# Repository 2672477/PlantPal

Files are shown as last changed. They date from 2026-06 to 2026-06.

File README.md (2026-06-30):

# PlantPal

---

# NOTE

This project was originally started for FALLOUT and is now being transferred to Horizons with permission from both organizers.

No funding was received from FALLOUT, and the project was never approved there. Since FALLOUT uses Lookout, I kindly request that project hours be evaluated based on my submitted journal entries.

AI tools were used during the initial planning and brainstorming phase of this project. All hardware design, firmware development, CAD modeling, assembly, testing, and documentation reflect own work.

P.S. - Permission was taken from @phthallo for doing it this way.

---

# Overview

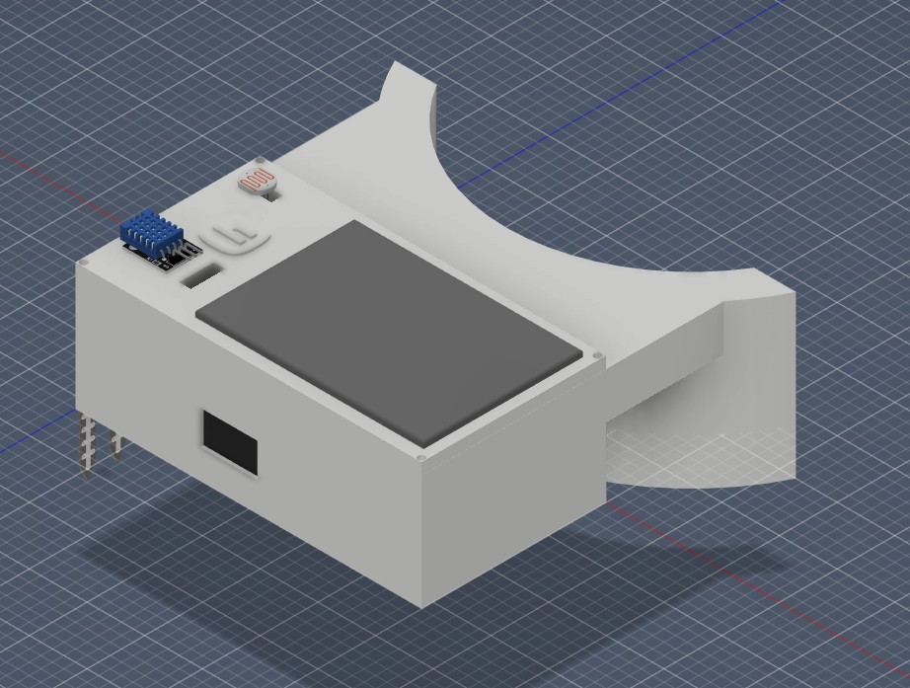
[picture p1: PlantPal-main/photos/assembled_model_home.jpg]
PlantPal


PlantPal is a solar-powered device that monitors the environment around a plant. It measures soil moisture, temperature, humidity, and light levels using an ESP32 and displays the plant's condition on a 0.96" OLED display.

Instead of showing raw sensor values, PlantPal displays simple expressions that make it easy to tell when a plant is healthy or needs attention. The goal was to make something that could be understood with a quick glance instead of opening an app or reading graphs.

The device runs from a rechargeable 18650 battery, while a small solar panel helps recharge it during the day.

---

# Why I Built It

I wanted to build a project that combined electronics, firmware, CAD, and 3D printing into one complete system.

While looking at existing plant monitoring projects, I noticed that most of them focused on displaying sensor values. That works well if you know what the numbers mean, but I wanted to try a different approach. Instead of expecting the user to interpret moisture percentages or light levels, PlantPal converts those readings into simple expressions on the display.

This project also gave me the opportunity to design my own enclosure, integrate solar charging, and build a complete embedded system instead of only testing sensors on a breadboard.

---

# Features

- Measures soil moisture
- Measures temperature and humidity
- Measures ambient light
- Displays the plant's condition on a 0.96" OLED display
- RGB LED status indicator
- Rechargeable 18650 battery
- Solar-assisted charging
- ESP32-WROOM-32 based hardware
- Custom designed 3D printed enclosure

---

# Project Gallery

## Fully Assembled Device

Main Assembly

## Side View

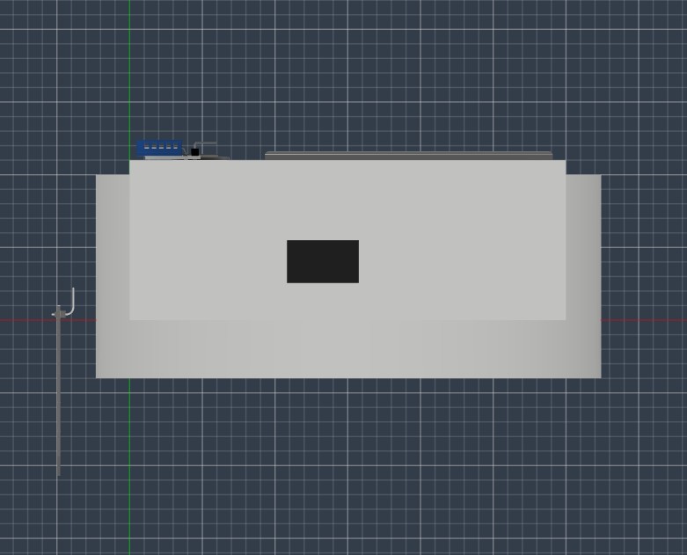
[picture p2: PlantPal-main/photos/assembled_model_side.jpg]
Side View


## Exploded View

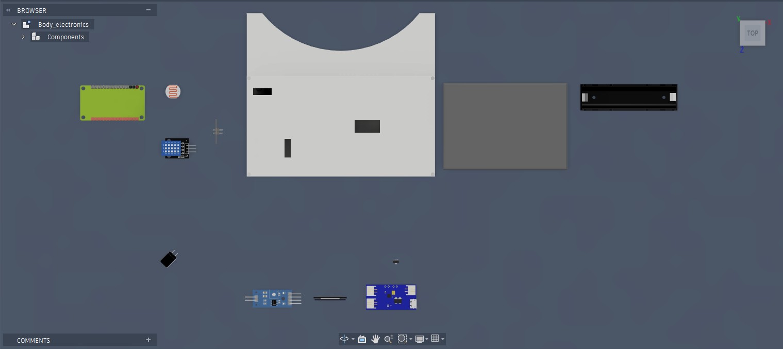
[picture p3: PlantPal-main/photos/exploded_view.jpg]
Exploded View


## Exploded View (Front)

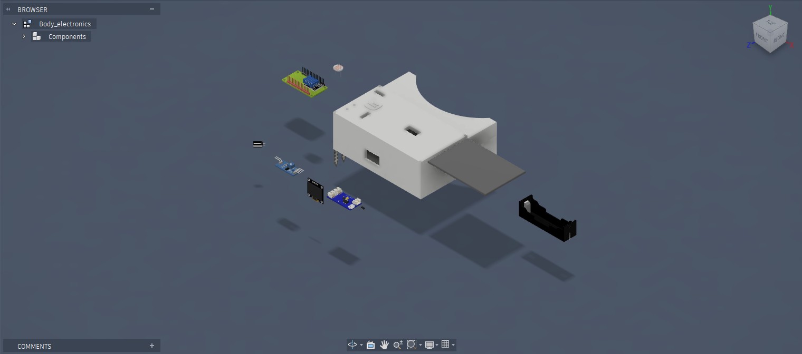
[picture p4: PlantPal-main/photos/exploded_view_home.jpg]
Exploded Front


## Exploded View (Side)

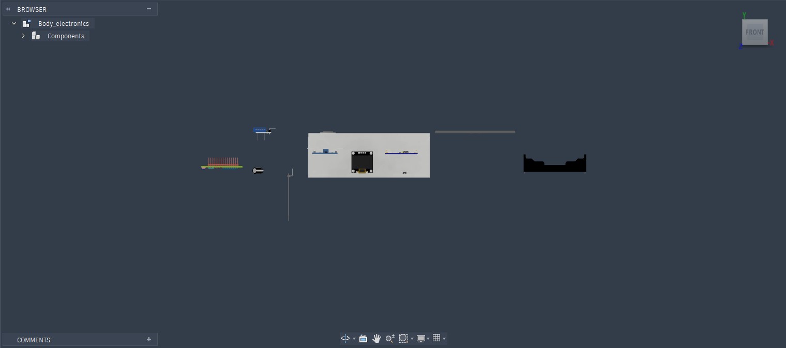
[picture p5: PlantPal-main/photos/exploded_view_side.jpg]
Exploded Side


These renders were useful while checking the fit of the internal components before printing the final enclosure.

---

# How It Works

PlantPal uses four sensors to monitor the plant's surroundings:

- Capacitive Soil Moisture Sensor
- AHT20 Temperature Sensor
- AHT20 Humidity Sensor
- BH1750 Light Sensor

Every few seconds, the ESP32 reads all four sensors and compares the values against predefined thresholds in the firmware.

Based on those readings, the firmware selects an expression that reflects the plant's overall condition. For example, dry soil or poor lighting will display an unhappy expression, while good growing conditions display a happy one.

The RGB LED also changes colour to match the current status, making it easy to check the plant from a distance.

Power is supplied by a rechargeable 18650 battery. A CN3065 solar charging board recharges the battery whenever the solar panel is exposed to sunlight.

---

# CAD Files

Designing the enclosure took several iterations because I needed to fit the battery, ESP32, display, charging circuit, sensors, and wiring into a compact space while keeping the device easy to assemble and service.

## Complete Assembly

- [STL File](PlantPal-main/cad/BODY_WITH_ELECTRONICS/Body_electronics.stl)

- [STEP File](PlantPal-main/cad/BODY_WITH_ELECTRONICS/Body_electronics.step)

## Individual Parts

All printable enclosure parts are available in:

```text
PlantPal-main/cad/PARTS
```

The repository also includes the source CAD files so the design can be modified or improved in the future.

---

# Hardware

PlantPal is built around an ESP32-WROOM-32 and uses commonly available components.

| Component | Purpose |
| --- | --- |
| ESP32-WROOM-32 | Main Controller |
| Capacitive Soil Moisture Sensor | Soil Moisture Measurement |
| AHT20 | Temperature & Humidity Measurement |
| BH1750 | Ambient Light Measurement |
| 0.96" OLED Display | Displays Plant Status |
| RGB LED | Visual Status Indicator |
| 18650 Battery | Main Power Source |
| CN3065 Solar Charger | Solar Battery Charging |
| HT7333-A LDO Regulator | 3.3V Voltage Regulation |
| 5V 2W Solar Panel | Solar Power Input |
| Custom 3D Printed Enclosure | Houses All Components |

---

# Bill of Materials

A complete list of components, supplier links, quantities, and prices is available here:

- [Bom.csv](PlantPal-main/Bom.csv)

The total hardware cost for this project is approximately **$18.39 USD**, excluding tools used during assembly.

---
# Wiring Diagram

I decided not to design a PCB for this version of PlantPal. Instead, all of the electronics are connected using hand wiring.

Before assembling everything, I recreated the circuit in KiCad to make sure all of the power and signal connections were correct. That made assembly much easier and helped catch mistakes before I started soldering.

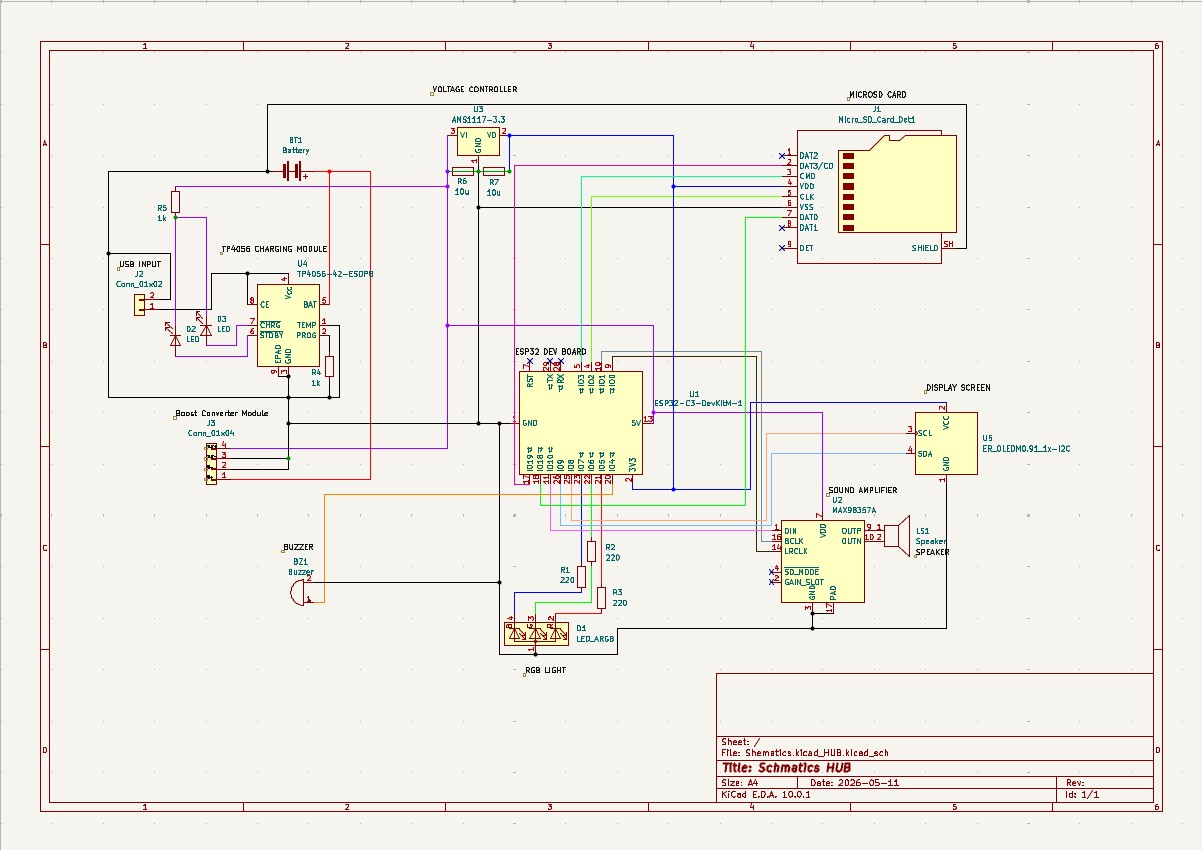
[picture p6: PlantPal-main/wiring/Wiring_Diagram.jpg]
Wiring Diagram


The wiring diagram includes:

- ESP32-WROOM-32
- Capacitive Soil Moisture Sensor
- AHT20 Temperature & Humidity Sensor
- BH1750 Light Sensor
- 0.96" OLED Display
- RGB LED
- CN3065 Solar Charging Circuit
- HT7333-A LDO Regulator
- 18650 Battery
- Solar Panel

Everything shown in the diagram matches the hardware used in the finished build.

---

# Building PlantPal

This repository includes the firmware, CAD files, wiring diagram, BOM, and assembly resources needed to recreate the project.

---

## 1. Print the Enclosure

Print all enclosure parts from:

```text
PlantPal-main/cad/PRINTING PARTS
```

After printing, install the M3 brass heat-set inserts into the enclosure.

The enclosure is designed around the components used in this build, making assembly straightforward while still allowing access for maintenance.

---

## 2. Prepare the Electronics

Use the BOM as a checklist and gather all required components.

Main components:

- ESP32-WROOM-32
- Capacitive Soil Moisture Sensor
- AHT20
- BH1750
- 0.96" OLED Display
- RGB LED
- CN3065 Solar Charger
- HT7333-A Regulator
- 18650 Battery
- Battery Holder
- Solar Panel

I tested each sensor individually before final assembly to avoid troubleshooting after everything was mounted.

---

## 3. Assemble the Hardware

Begin installing the components inside the enclosure.

The enclosure includes mounting locations for:

- ESP32
- OLED Display
- Battery Holder
- Charging Board
- Voltage Regulator

Fitting everything inside the enclosure took several layout revisions. The final design leaves enough room for wiring and can still be opened later if a component needs replacing.

---

## 4. Complete the Wiring

Follow the wiring diagram while soldering the connections.

Main connections include:

- I²C bus for the OLED, AHT20, and BH1750
- Soil moisture sensor output
- RGB LED outputs
- Battery connections
- Solar charging circuit
- 3.3V power rail

Double-check all power connections and verify there are no shorts before connecting the battery.

---

## 5. Upload the Firmware

The firmware is located in:

```text
PlantPal-main/firmware
```

Upload it using Arduino IDE or PlatformIO.

The firmware handles:

- Reading all sensors
- Processing the sensor values
- Choosing the correct plant expression
- Updating the OLED display
- Controlling the RGB LED

Once uploaded, the ESP32 starts monitoring automatically.

---

# Using PlantPal

After startup, the device continuously monitors the plant and updates the display every few seconds.

1. Insert the soil moisture sensor into the plant pot.
2. Place the device where the solar panel can receive sunlight.
3. Power on the device.
4. Wait a few seconds for the first sensor readings.

Once running, PlantPal updates automatically.

The OLED displays the current condition of the plant, while the RGB LED provides a quick status indication that can be seen from a distance.

No app or additional setup is required after powering on.

---

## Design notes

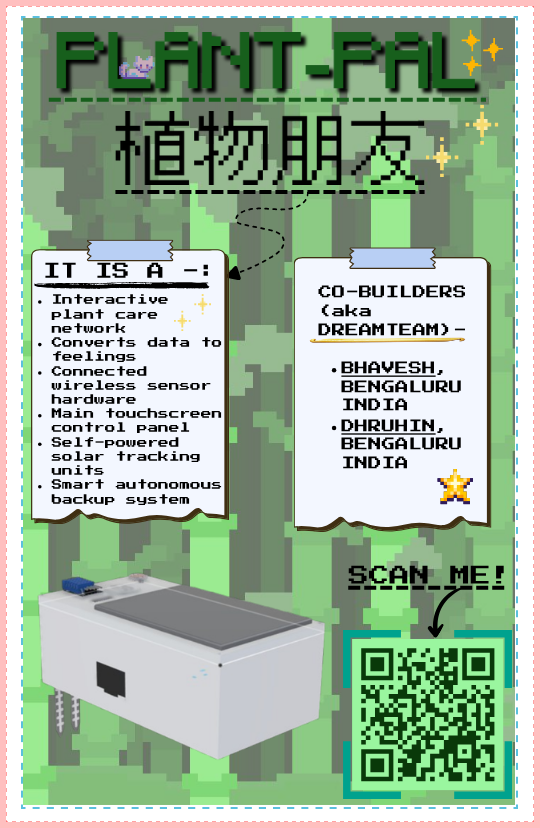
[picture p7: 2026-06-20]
PlantPal-main/zine/ZINE_PLANT-PAL.png

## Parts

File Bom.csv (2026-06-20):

Product Name | Description | Quantity | Unit Price($) | Total Price($) | URL
ESP32-WROOM-32 Dev Board | WiFi + BLE Microcontroller | 1 | 4.06 | 4.06 | https://robocraze.com/products/nodemcu-32-wifi-bluetooth-esp32-development-board30-pin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
Capacitive Soil Moisture Sensor v1.2 | Soil Moisture Sensor | 1 | 0.65 | 0.65 | https://www.flipkart.com/ziobotics-5v-soil-moisture-sensor-module-pack-1-plant-monitoring-smart-irrigation-electronic-components-hobby-kit/p/itm347f17fdb44c8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
AHT20 | Temperature Sensor | 1 | 1.34 | 1.34 | https://robocraze.com
GY-302 BH1750 | Light Intensity Sensor | 1 | 1.42 | 1.42 | https://robocraze.com/products/gy-302-bh1750-light-intensity-module?_pos=1&_sid=4a6498e1f&_ss=r
0.96' OLED | Display | 1 | 1.69 | 1.69 | https://robocraze.com/products/0-96in-oled-display-module-4pin?_pos=1&_sid=8ccd9ded7&_ss=r
18650 Li-ion Battery | Battery | 1 | 0.73 | 0.73 | https://robocraze.com/products/3-7v-2000mah-18650-li-ion-battery?_pos=1&_sid=a3bd80eec&_ss=r
18650 Li-ion Battery Holder | Battery Holder | 1 | 0.17 | 0.17 | https://robocraze.com/products/18650-1-cell-holder?_pos=2&_sid=ca0d8ced4&_ss=r
TP4056 Charging Module | USB-C Backup Charger Module | 1 | 0.15 | 0.15 | https://robocraze.com/products/tp4056-battery-charger-c-type-module-with-protection-1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
CN3065 Solar Charger Board | Dedicated Solar MPPT Management | 1 | 0.88 | 0.88 | https://robu.in/product/mini-solar-lipo-charger-board/?gad_source=1&gad_campaignid=17427802559
HT7333-A LDO Regulator | Ultra-Low Power 3.3V Regulator | 1 | 0.48 | 0.48 | https://robu.in/product/ht7333-a-holtek-semicon-250ma-fixed-3-3v-positive-electrode-12v-sot-89-3-voltage-regulators-linear-low-drop-out-ldo-regulators-rohs/
16V Radial Electrolytic Capacitor (470uF) | Wi-Fi Power Spike Smoother | 1 | 0.18 | 0.18 | https://robu.in/product/16yxf470mffc10x12-5-rubycon-470uf-16v-160mω100khz-±20-580ma100khz-plugind10xl12-5mm-aluminum-electrolytic-capacitors-leaded-rohs/?gad_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
10k Ohm Quarter Watt Resistors | Pull-up & LDR Voltage Divider | 1 | 0.14 | 0.14 | https://robocraze.com/products/10k-resistor-pack-of-10?_pos=1&_sid=c78a5a957&_ss=r
220 Ohm Quarter Watt Resistors | RGB LED Current Limiters | 1 | 0.095 | 0.095 | https://robocraze.com/products/220-ohm-resistor-pack-of-10?_pos=1&_sid=8a82cca51&_ss=r
5V - 2W Solar Panel | Solar Panel | 1 | 0.98 | 0.98 | https://quartzcomponents.com/products/portable-mini-solar-panel-1-1w-6v-180ma-99-x-69mm?variant=44789436252394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
Male to Female Jump Wires | Wires | 1 | 0.45 | 0.45 | https://robocraze.com/products/f2m-jumper-wires-20cm-40pcs?variant=40192519110809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
Male to Male Jump Wires | Wires | 1 | 0.49 | 0.49 | https://robocraze.com/products/m2m-jumper-wires-20cm-40pcs?_pos=1&_sid=2e3cb64b0&_ss=r
Female to Female Jump Wires | Wires | 1 | 0.45 | 0.45 | https://robocraze.com/products/f2f-jumper-wires-20cm-40pcs?_pos=1&_sid=51c4faba8&_ss=r
M3 X 5 mm Brass Heat Threaded Round Insert Nut | Heat-Set Inserts | 10 | 0.025 | 0.25 | https://onlyscrews.in/products/m3-x-5mm-brass-threaded-inserts-dia-3mm-length-5mm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
M3 x 8mm Button Head Screws | Enclosure Assembly Fasteners | 10 | 0.028 | 0.28 | https://onlyscrews.in/products/m3-x-8mm-hex-allen-button-head-hight-tensile10-9-black-oxide-screw-dia-3mm-length-8mm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
3d Printed Enclosure | Custom Enclosure | 1 | 3.50 | 3.50 | forms.hackclub.com/print-legion-signup
Total |  |  |  | 18.385

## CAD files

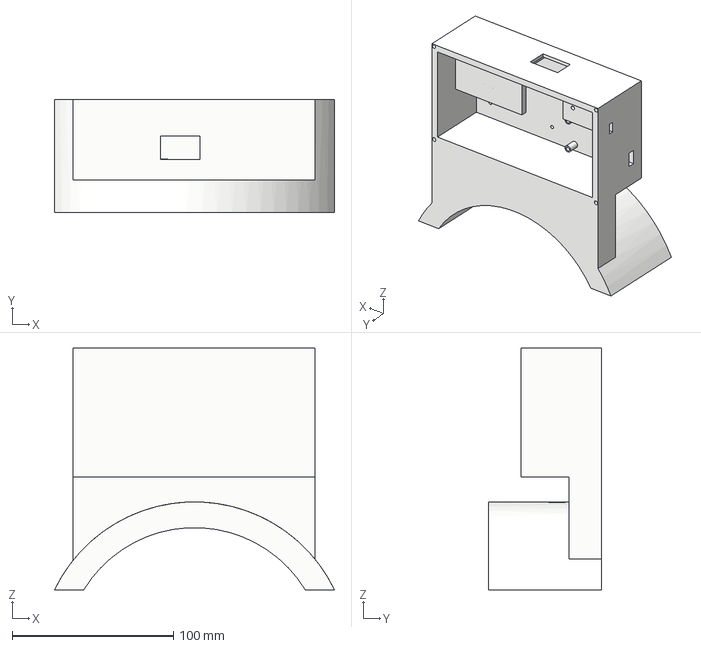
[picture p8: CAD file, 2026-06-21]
PlantPal-main/cad/PRINTING PARTS/BODY/Main_Body.step
173.8 x 70.0 x 150.0 mm

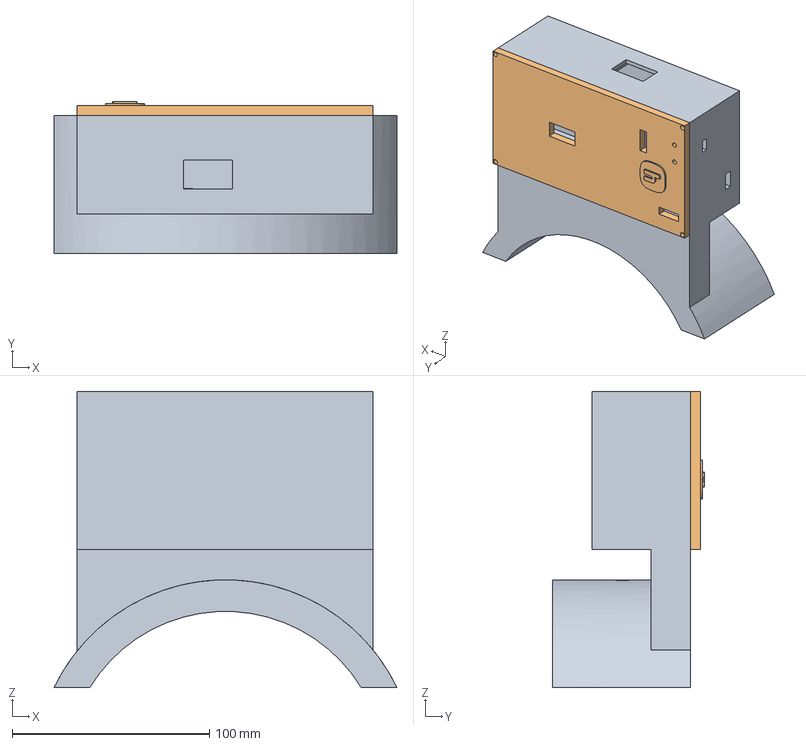
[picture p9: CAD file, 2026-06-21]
PlantPal-main/cad/BODY/Body_electronics.step
173.8 x 77.0 x 150.0 mm

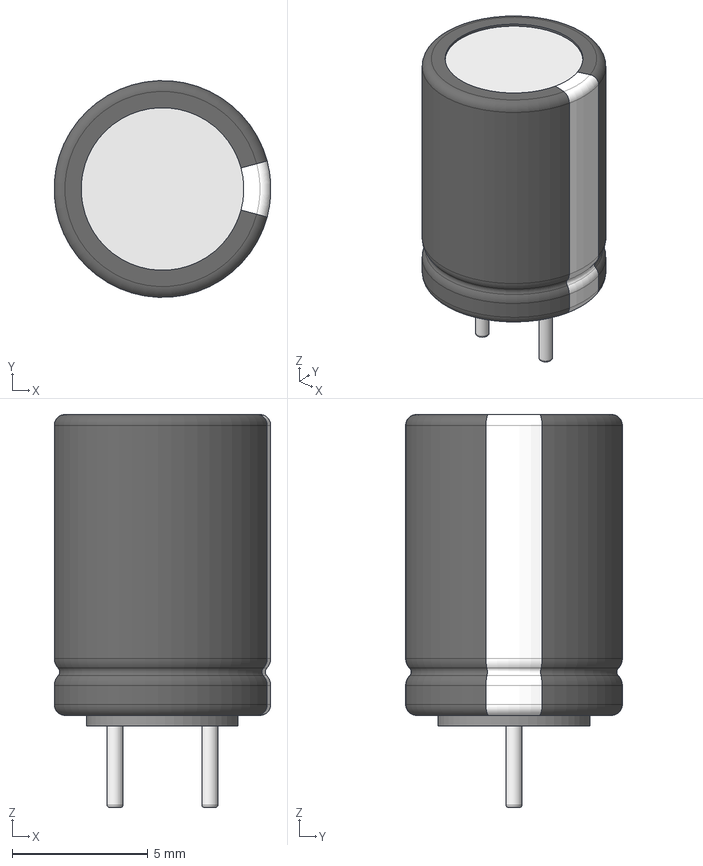
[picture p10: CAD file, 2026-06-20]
PlantPal-main/cad/PARTS/Capacitor/Aluminum_electrolytic_capacitor_radial_D8_H11.5_PinD0.6_Pitch3.5_nominal_black.step
7.99 x 7.99 x 14.5 mm

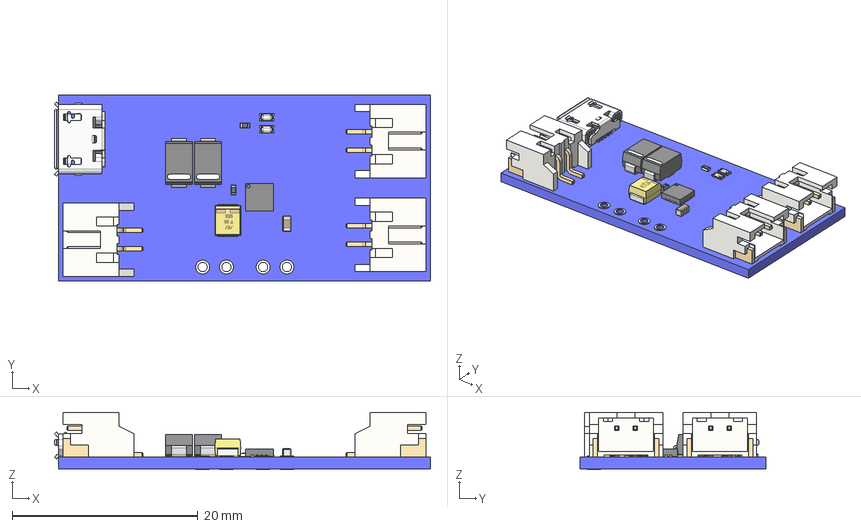
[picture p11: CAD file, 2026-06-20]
PlantPal-main/cad/PARTS/CN3065 Solar Charger/CN3065 Solar Charger board.step
40.4 x 20.0 x 6.17 mm

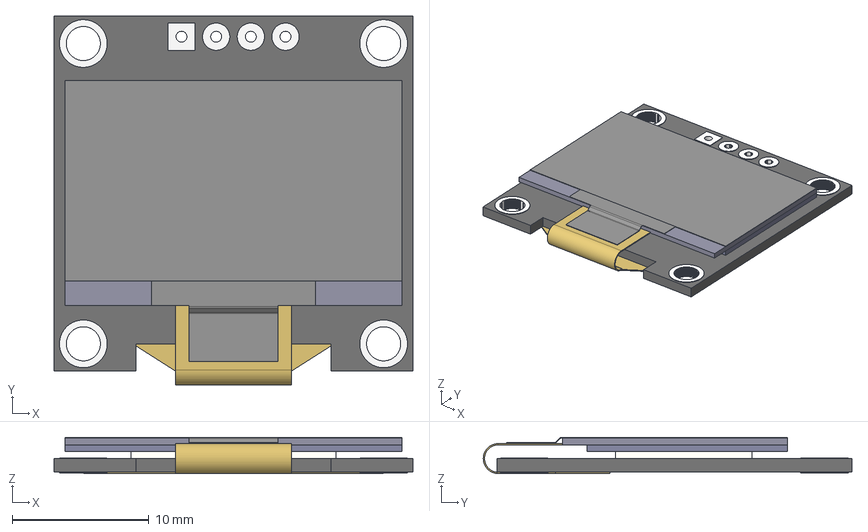
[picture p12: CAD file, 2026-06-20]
PlantPal-main/cad/PARTS/Display_OLED/Display_OLED_0.96_128x64.step
26.3 x 27.0 x 2.65 mm

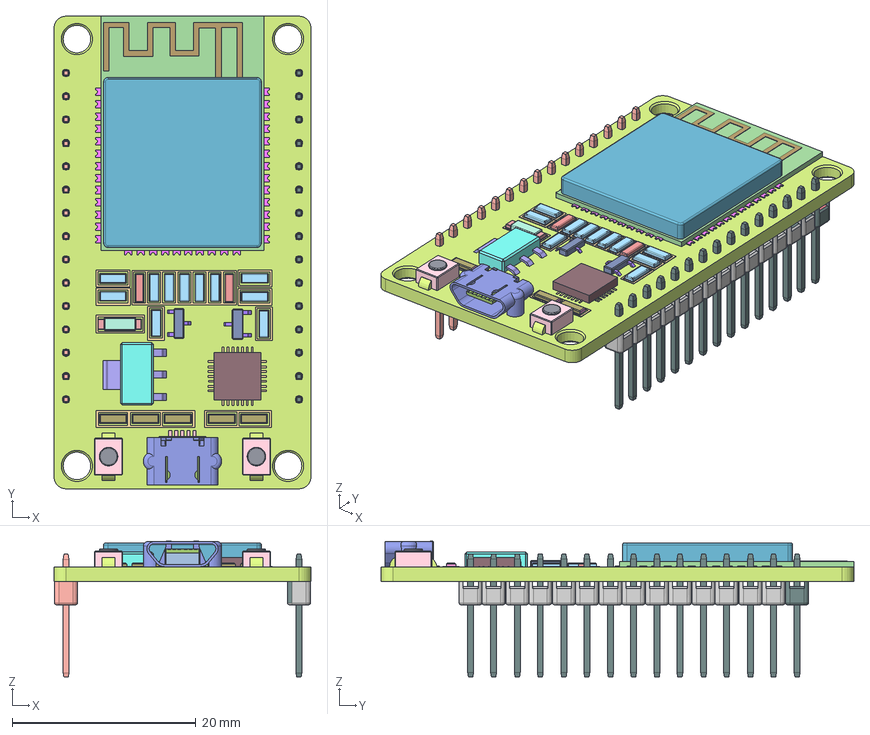
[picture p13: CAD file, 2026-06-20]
PlantPal-main/cad/PARTS/ESP32 dev kit/ESP32 dev Kit v1.step
28.0 x 51.5 x 14.8 mm

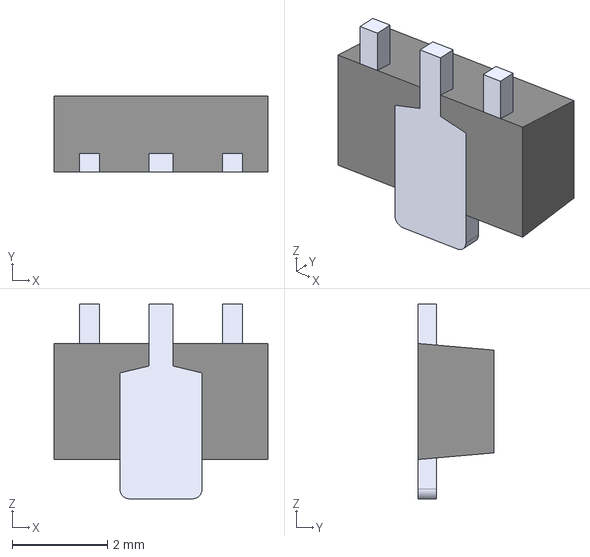
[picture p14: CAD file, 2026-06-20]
PlantPal-main/cad/PARTS/HT7333--3DModel/HT7333--3DModel-STEP-510211.step
4.50 x 1.60 x 4.09 mm

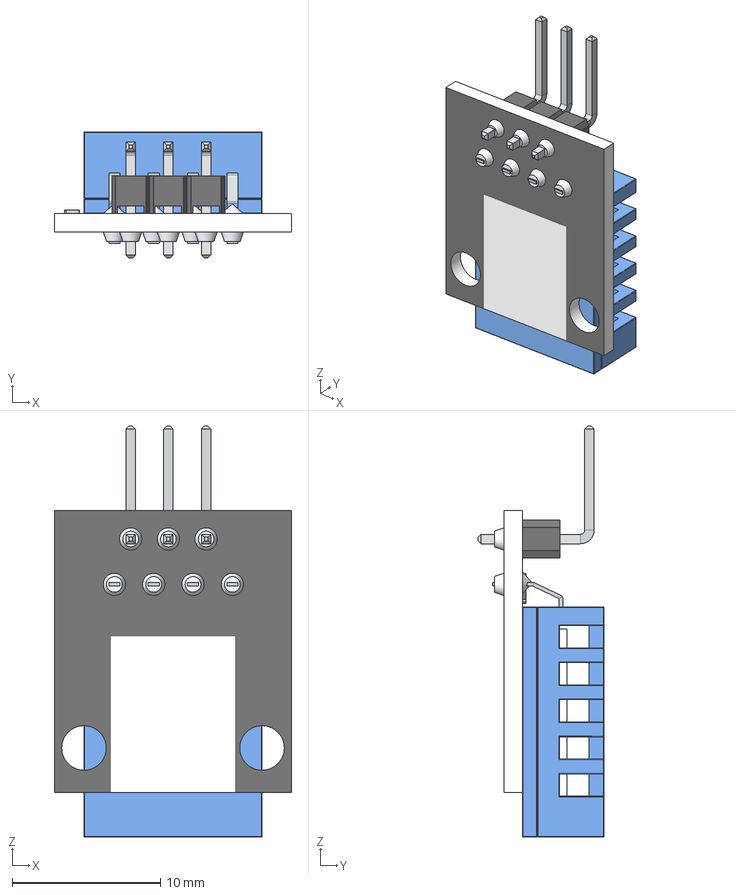
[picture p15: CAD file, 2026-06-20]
PlantPal-main/cad/PARTS/KY-015/KY-015 (1).step
16.0 x 8.50 x 27.7 mm

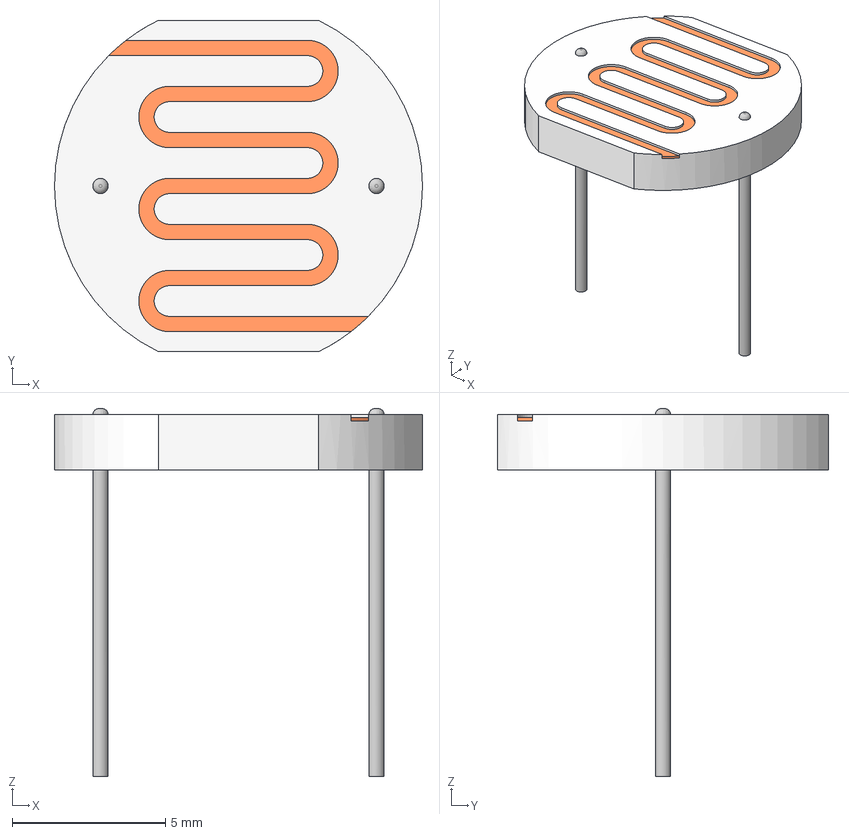
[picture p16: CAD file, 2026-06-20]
PlantPal-main/cad/PARTS/LDR12/LDR12.step
12.0 x 10.8 x 12.0 mm

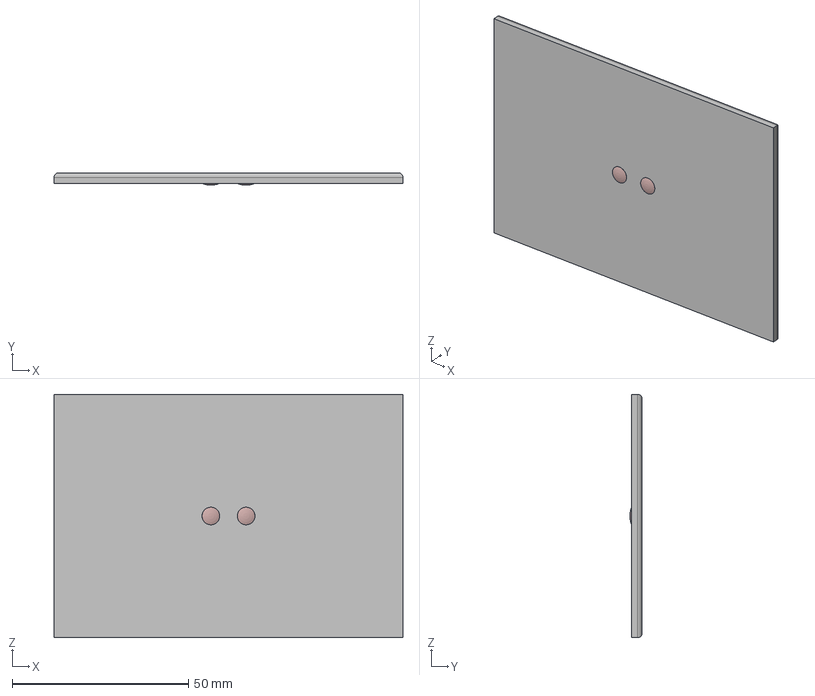
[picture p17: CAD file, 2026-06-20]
PlantPal-main/cad/PARTS/Polycrystalline Solar Panel/Polycrystalline Solar Panel, 5 V, 200 mA.step
99.0 x 3.51 x 69.0 mm

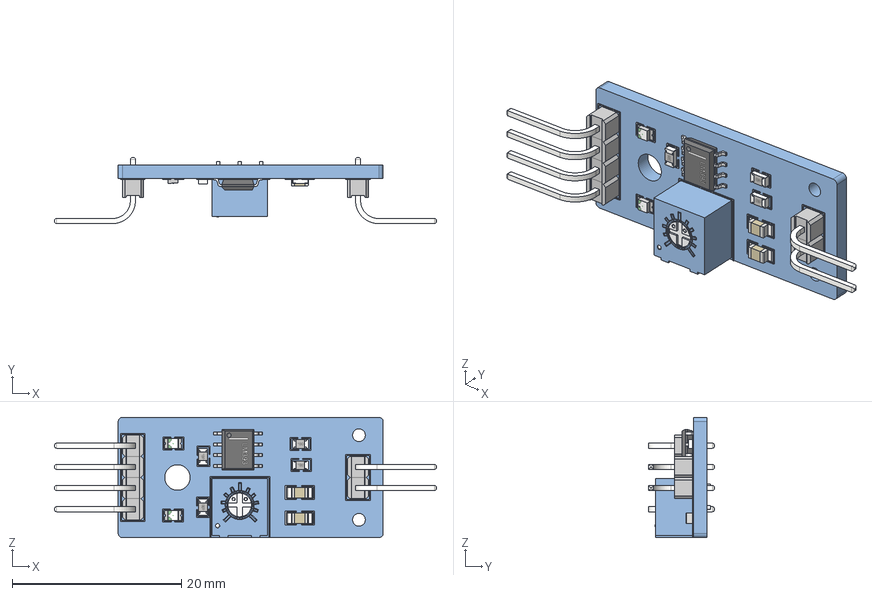
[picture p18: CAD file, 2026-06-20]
PlantPal-main/cad/PARTS/Soil Moisture Sensor Board/Soil Moisture Sensor Board.step
45.1 x 7.80 x 14.2 mm

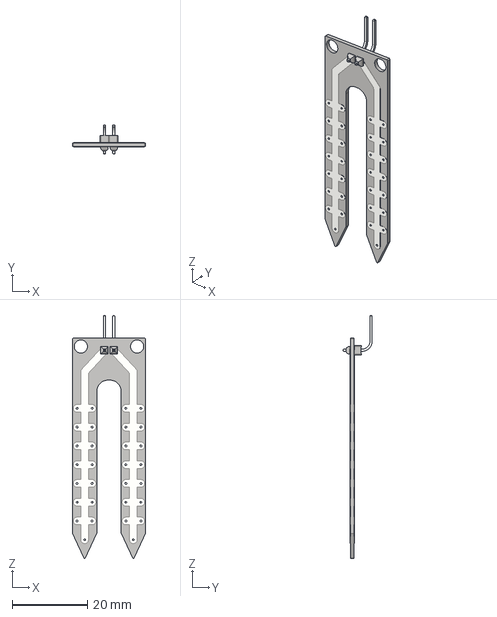
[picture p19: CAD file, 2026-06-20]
PlantPal-main/cad/PARTS/Soil Moisture Sensor/soil moisture sensor.step
19.5 x 7.80 x 64.7 mm

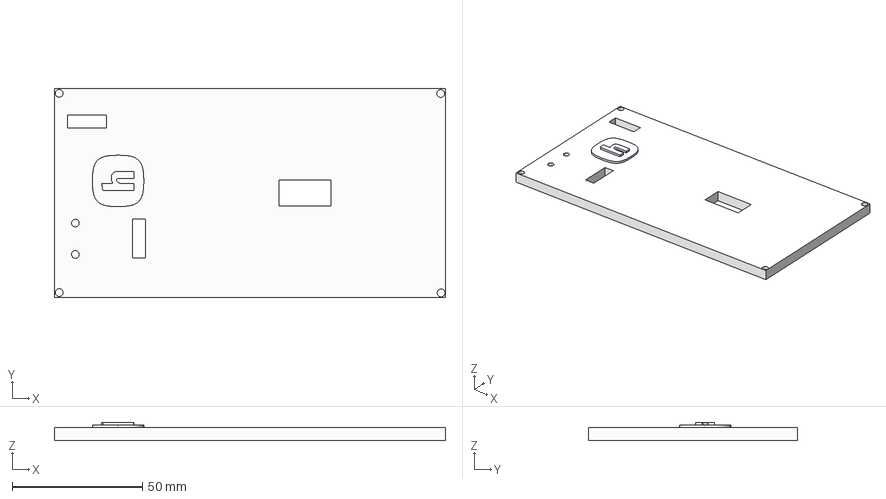
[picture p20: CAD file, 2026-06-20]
PlantPal-main/cad/PRINTING PARTS/LID/Lid.step
150.0 x 80.0 x 7.00 mm

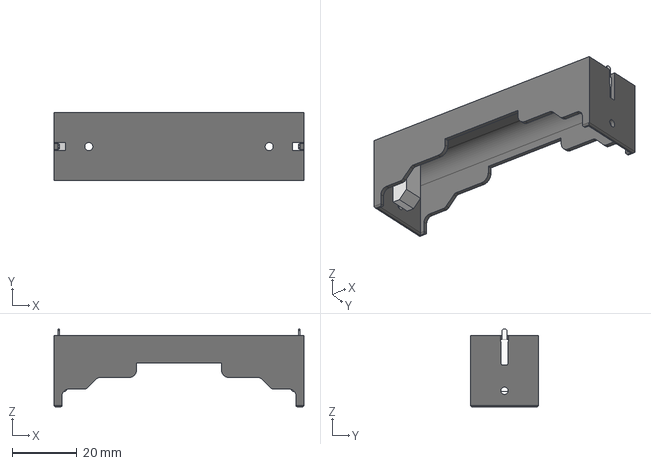
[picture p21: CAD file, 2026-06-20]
PlantPal-main/cad/PARTS/Battery Holder/18650-battery-and-holder-02b.step
77.3 x 21.0 x 24.1 mm

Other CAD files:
PlantPal-main/cad/PARTS/Battery Holder/18650-battery-and-holder-02b.f3d
PlantPal-main/cad/PARTS/CN3065 Solar Charger/CN3065 Solar Charger board.f3d
PlantPal-main/cad/PARTS/Capacitor/Aluminum_electrolytic_capacitor_radial_D8_H11.5_PinD0.6_Pitch3.5_nominal_black.f3d
PlantPal-main/cad/PARTS/Display_OLED/Display_OLED_0.96_128x64.f3d
PlantPal-main/cad/PARTS/ESP32 dev kit/ESP32 dev Kit v1.f3d
PlantPal-main/cad/PARTS/HT7333--3DModel/HT7333--3DModel-STEP-510211.f3d
PlantPal-main/cad/PARTS/KY-015/KY-015 (1).f3d
PlantPal-main/cad/PARTS/LDR12/LDR12.f3d
PlantPal-main/cad/PARTS/Polycrystalline Solar Panel/Polycrystalline Solar Panel, 5 V, 200 mA.f3d
PlantPal-main/cad/PARTS/Soil Moisture Sensor Board/Soil Moisture Sensor Board.f3d
PlantPal-main/cad/PARTS/Soil Moisture Sensor/soil moisture sensor.f3d
PlantPal-main/cad/PRINTING PARTS/BODY/Main_Body.f3d
PlantPal-main/cad/PRINTING PARTS/LID/Lid.f3d

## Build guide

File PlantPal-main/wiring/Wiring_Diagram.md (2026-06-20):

# 🧠 PLANTPAL NODE CONNECTIONS

### ESP32-C3 DEV BOARD
* **3.3V Pin** <- **HT7333-A VOUT** (Direct low-power supply)
* **GND** <- Common GND
* **470µF Capacitor (+)** -> Solder directly to ESP32 **3.3V Pin**
* **470µF Capacitor (-)** -> Solder directly to ESP32 **GND Pin**

---

### SOIL MOISTURE SENSOR (Power-Gated)
* **VCC** -> **IO2** (ESP32 pin controls power ON/OFF)
* **GND** -> GND
* **DO** -> Not Connected
* **AO** -> **IO0**

---

### LIGHT INTENSITY SENSOR (LDR)
* **Top Pin** -> **3.3V Pin**
* **Bottom Pin** -> **IO1**
* **IO1** -> 10kΩ Resistor -> GND

---

### DHT11 TEMPERATURE + HUMIDITY SENSOR (Power-Gated)
* **1(VDD)** -> **IO3** (ESP32 pin controls power ON/OFF)
* **2(DATA)** -> **IO4**
* **4(GND)** -> GND
* **DATA** -> 10kΩ Resistor -> **IO3** (Pull-up connects to gated power)

---

### RGB LED
* **1(GND)** -> GND
* **2(RED)** -> 220Ω Resistor -> **IO5**
* **3(GREEN)** -> 220Ω Resistor -> **IO6**
* **4(BLUE)** -> 220Ω Resistor -> **IO7**

---

### 0.96" OLED DISPLAY (Power-Gated)
* **1(GND)** -> GND
* **2(VCC)** -> **IO10** (ESP32 pin controls power ON/OFF)
* **3(SCL)** -> **IO8**
* **4(SDA)** -> **IO9**

---

### SOLAR PANEL
* **+VE** -> **CN3065 VIN**
* **-VE** -> **CN3065 GND**

---

### SOLAR CHARGING MODULE (CN3065)
* **TEMP** -> GND
* **ISET** -> 2kΩ Resistor -> GND
* **GND** -> GND
* **VIN** -> Solar Panel +
* **BAT** -> Battery +
* **FB** -> BAT
* **VIN** -> 10µF Capacitor -> GND
* **BAT** -> 10µF Capacitor -> GND
* **VIN** -> 1kΩ Resistor -> LED -> DONE
* **VIN** -> 1kΩ Resistor -> LED -> CHRG

---

### TP4056 BATTERY CHARGING MODULE (USB-C Backup)
* **TEMP** -> GND
* **PROG** -> 1kΩ Resistor -> GND
* **GND** -> GND
* **VCC** -> USB-C 5V
* **BAT** -> Battery +
* **CE** -> VCC
* **EPAD** -> GND Copper Plane
* **VCC** -> 1kΩ Resistor -> LED -> STDBY
* **VCC** -> 1kΩ Resistor -> LED -> CHRG

---

### 18650 BATTERY
* **+VE** -> TP4056 BAT+ / CN3065 BAT+ / **HT7333-A VIN**
* **-VE** -> GND

---

### HT7333-A LDO REGULATOR 
* **Pin 1 (GND)** -> Common GND
* **Pin 2 (VIN)** -> **Battery +**
* **Pin 3 (VOUT)** -> **ESP32 Dev Board 3.3V Pin**

---

### 🔌 COMMON GROUND
ALL GND CONNECTIONS MUST BE CONNECTED TOGETHER:
* ESP32
* TP4056
* Battery (-)
* OLED
* RGB LED
* DHT11
* LDR (via 10kΩ Resistor)
* Moisture Sensor
* Solar Charging Module
* HT7333-A (Pin 1)
* 470µF Buffer Capacitor (-)

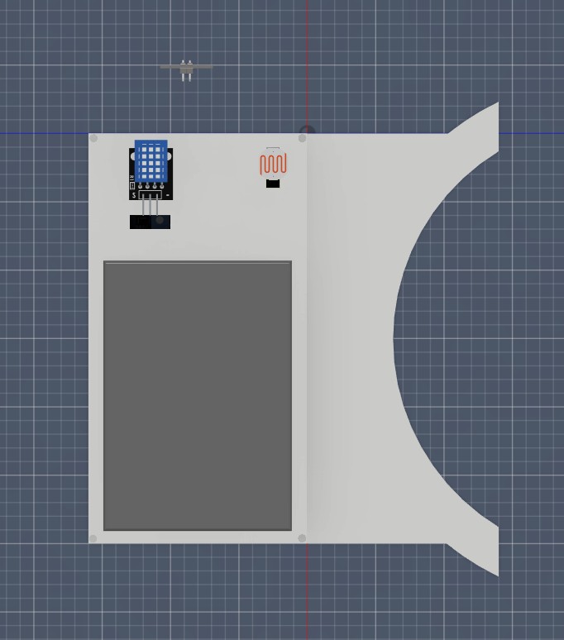
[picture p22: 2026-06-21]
PlantPal-main/photos/assembled_model_top.jpg

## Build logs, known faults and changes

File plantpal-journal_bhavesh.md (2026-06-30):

## NOTE: 
The remaining journal entries are of my teammate, thus are not included in my journal as fallout takes both together in one. These are all my hrs/journals. I have taken permission from Horizons team to do this.
Thank you!
This project was originally started for Fallout and is now being transferred to Horizons with permission from both organisers.
No funding was received from Stasis, and the project was never approved there. Since Fallout uses LOOKOUT, I kindly request that project hours be evaluated based on my submitted journal entries.
Thank you for your consideration.
## Total time spend
### FALLOUT HRS-37.9 hrs
### HACKATIME HRS-0.9
## TOTAL=38.8 HRS

# PlantPal — Journal Export

- Exported at: 2026-06-20T16:10:05Z
- Project ID: 2370
- Entries: 23

## Entry 3
- ID: 5917
- Author: bhaveshtushar123
- Created At: 2026-05-07T16:06:18Z

### Content

today was mostly focused on understanding the electronics and planning side of the new project with Dhruhin <3. we finalized a rough component list for both the PlantPal node and hub systems, which honestly made the whole idea feel way more real instead of just random thoughts on paper. we discussed how sensors, displays, power modules, and communication between the two ESP32 boards would work together.

i also spent time learning schematics properly and understanding how components connect logically before actually wiring anything. after that i downloaded KiCAD for the first time and started exploring the software for making schematics and future pcb work. ngl it looked super confusing at first bruh, but after watching tutorials and clicking around it slowly started making sense.

not a huge building day physically, but definitely important because now i understand the project architecture and electronics workflow way better yay.



### Recording Links

- https://lookout.hackclub.com/api/media/5ab33579-50ad-4a1c-97a9-db52b238f06b/video.mp4

## Entry 5
- ID: 6108
- Author: bhaveshtushar123
- Created At: 2026-05-08T16:37:24Z

### Content

Today I worked on the KiCad schematic again. Added the ESP32, OLED display, RGB LED, moisture sensor, temperature sensor, light sensor, solar charging module, battery charging module, and battery. Did most of the GND connections too, which took longer than expected because of all the wires crossing everywhere.

Also connected some parts of the solar panel circuit to the charging module. Added resistors and capacitors where needed. Mostly spent time moving things around and checking connections because some stuff was connected wrong the first time.

Overall, it was just schematic work for most of the day.

Schmatics-:



### Recording Links

- https://lookout.hackclub.com/api/media/1f7b8eaa-c1c9-4452-80d6-fc069befb9ee/video.mp4
- https://lookout.hackclub.com/api/media/6279dd45-151a-4eea-8f6b-39d9115646f6/video.mp4

## Entry 7
- ID: 6278
- Author: bhaveshtushar123
- Created At: 2026-05-09T15:53:52Z

### Content

Today I’ve been working on the TP4056 charging circuit in KiCad. Connected the battery, 5V input, GND and the BAT pin connections correctly. Also added the charging and standby LEDs with the resistors so that the charging status can be shown physically later.

Spent most of the time checking the pin connections as the TP4056 pins were easy to mix up. Had to redo some wires after seeing a couple of mistakes in the layout. wired up the PROG pin resistor as well, and did some cleanup of the schematic to make the wiring look less confusing.

I mostly worked on charging circuits today and fixed small connection problems.




### Recording Links

- https://lookout.hackclub.com/api/media/37b36937-bbb7-4d18-b73c-07ce0e945bd3/video.mp4

## Entry 8
- ID: 6447
- Author: bhaveshtushar123
- Created At: 2026-05-10T16:13:37Z

### Content

Today was mostly wiring work for the PlantPal schematic. Connected almost all the remaining parts including the sensors, OLED display, RGB LED, TP4056 module, solar charging module, battery, and boost converter with the ESP32. Spent a lot of time routing wires properly because the schematic was getting messy and some connections kept overlapping.

After that I went back and rechecked the whole circuit again to make sure the current flow and power connections actually made sense. Also had to decide GPIO pins properly depending on analog support, I2C, PWM, and avoiding ESP32-C3 boot issue pins. Found and fixed a few wrong connections during checking too.

Also helped another Hack Cluber for a bit because she DM’d me asking about KiCad and wiring problems.

SCHEMATICS-


NOTEPAD-



### Recording Links

- https://lookout.hackclub.com/api/media/7065059a-00b2-42a5-b121-e7af8bd39af5/video.mp4
- https://lookout.hackclub.com/api/media/04546d30-af83-4f61-9567-41a2cfead865/video.mp4

## Entry 10
- ID: 6610
- Author: bhaveshtushar123
- Created At: 2026-05-11T16:34:08Z

### Content

Journal Entry, Day __

Today, I color-coded much of the node wiring in KiCad to make the schematic easier to read. The wires became confusing after I added all the sensors, charging modules, OLED, RGB LED, and power connections. Then, I rechecked the entire node schematic to confirm the current flow, GPIO pins, and power routing were correct.

After that, I completed most of the hub schematic, including the audio amplifier, speaker, OLED, MicroSD, regulator, TP4056, and ESP32 connections. I spent some time double-checking all the connections because there were many overlapping communication and power lines.

I also exported the schematic files and organized them in the file explorer before starting CAD tomorrow.
NODE-


HUB-


### Recording Links

- https://lookout.hackclub.com/api/media/11ef0c32-c5c4-484f-8737-61aee74f9471/video.mp4
- https://lookout.hackclub.com/api/media/53a89df3-de79-4e76-8606-135fc017e0b2/video.mp4
- https://lookout.hackclub.com/api/media/eacdf0fa-082c-4c86-b559-8ba7f5f7aea2/video.mp4

## Entry 14
- ID: 6958
- Author: bhaveshtushar123
- Created At: 2026-05-13T17:38:13Z

### Content

Today I started making a rough layout of the project in Paint first so I could plan where all the electronics would actually fit before doing proper CAD. It helped me figure out spacing and placement for the ESP32, battery, sensors, OLED, charging module, boost converter, and wiring paths without making the Autodesk file messy immediately.
After that I started adding all the electronics into Autodesk and placing components roughly inside the model. Most of the time went into checking dimensions, arranging parts so they would physically fit, and trying to keep wiring space available. Also had to keep changing placements because some components were overlapping or taking more space than expected.




### Recording Links

- https://lookout.hackclub.com/api/media/19227290-0214-49de-aecf-73635e859d86/video.mp4
- https://lookout.hackclub.com/api/media/39ec9275-5b34-49c3-b704-0bd5c9d1d179/video.mp4

## Entry 16
- ID: 7079
- Author: bhaveshtushar123
- Created At: 2026-05-14T13:52:37Z

### Content

Today I worked more on the Autodesk model and started adding some of the main electronics into the enclosure. Added the OLED display, ESP32, MT3608 boost converter, 18650 battery, and AMS1117 regulator roughly in their positions to check spacing and layout. Had to move parts around a lot because some components were larger than expected and the wiring space was getting cramped.

Also made an internal platform/support structure inside the model so more electronics could be mounted properly instead of everything floating around randomly. Spent some time adjusting heights and placements so components could stack better and still leave space for wires and future additions.





### Recording Links

- https://lookout.hackclub.com/api/media/3a23301c-8656-4666-a354-427e7738438a/video.mp4

## Entry 18
- ID: 7276
- Author: bhaveshtushar123
- Created At: 2026-05-15T15:57:34Z

### Content

Today, I focusd mainly on the CAD model and completed most of the main structure for the node. I added more components to the enclosure, including the DHT11 sensor, LDR, solar panel, and the Hack Club logo to the design. I spent a lot of time adjusting placements and dimensions to ensure everything fit well without overlapping internally. I also created holes and cutouts for wires, screws, sensors, and mounting points since the enclosure was mostly solid before. I changed the render and material settings too, making the model look cleaner and easier to visualise. Most of the CAD work is done now, aside from a few small adjustments and final details. Also added lid, forgot that part.

ELECTRONICS-

LID-

MAIN-


### Recording Links

- https://lookout.hackclub.com/api/media/62b85ff0-1776-4982-bd3c-866d370d4d17/video.mp4
- https://lookout.hackclub.com/api/media/e16ffa62-e9bf-44ba-a7a8-ef37866cbf37/video.mp4
- https://lookout.hackclub.com/api/media/b78c2c9e-9d7b-4c64-90aa-9508c52582d8/video.mp4

## Entry 21
- ID: 14029
- Author: bhaveshtushar123
- Created At: 2026-06-14T17:11:51Z

### Content

Today I started working on the Zine for the project. Since I had never really made one before, a lot of the time went into figuring out how everything should be laid out and what information was actually important to include. I worked on organizing the content, planning pages, and trying to make it look less cluttered while still explaining the project properly.

During Fallout Lock-In 2, I also learned how to use Figma from Rehan. He showed me some of the basics, like working with frames, arranging elements, and making designs look cleaner. I used some of those things while working on the Zine.

Apart from that, I spent time hanging out with Renran and a few other people during the event. We talked, messed around, and had a lot of fun while working, which made the whole session much more enjoyable.

zine-


### Recording Links

- https://lookout.hackclub.com/api/media/140d17be-c9f9-49db-b658-40af07913806/video.mp4
- https://lookout.hackclub.com/api/media/5c043b82-5789-4a20-974e-6d6c678c438f/video.mp4

## Entry 22
- ID: 14574
- Author: bhaveshtushar123
- Created At: 2026-06-16T17:07:38Z

### Content

Journal Entry — Day __

Today I worked more on the CAD model and made a few important design changes before moving closer to a final version. I went through the enclosure again and checked that all the screw holes were properly placed and aligned so the different parts could be assembled securely. I also adjusted some dimensions and placements to make sure the components would fit correctly inside the enclosure.

On the electronics side, I updated the design by simplifying the power system. I removed the MT3608 boost converter and AMS1117 regulator from the project and replaced them with an HT7333-A LDO regulator along with a 16V radial electrolytic capacitor. This made the circuit simpler, reduced the number of components, and helped save space inside the enclosure. After making the changes, I updated the CAD layout to match the new electronics arrangement and checked that everything still fit properly.



### Recording Links

- https://lookout.hackclub.com/api/media/3869ff6c-a1b9-4fa5-9c12-3c610f5561af/video.mp4

## Entry 23
- ID: 15568
- Author: bhaveshtushar123
- Created At: 2026-06-20T12:16:36Z

### Content

Today was mostly focused on documentation and final project organization. I spent a good amount of time going through the entire project again and updating the README so it accurately reflected the current version of PlantPal. Since the hub had been removed from the project, I had to rewrite several sections, update the hardware list, BOM, architecture, setup instructions, and add proper descriptions for how the device works.

I also organized the repository structure, added links to the CAD files, wiring diagrams, and project assets, and made sure all the renders and images were included in the documentation. A lot of time went into deciding what information was actually important and removing sections that were either outdated or repetitive.

Along with that, I reviewed the BOM again, checked component selections, and verified that the documentation matched the latest CAD and electronics design. By the end of the day, the project felt much more complete and easier for someone new to understand without needing to open additional files.


### Recording Links

- https://lookout.hackclub.com/api/media/ad1d62ed-e7c8-4d50-b121-b4235400ed38/video.mp4
- https://lookout.hackclub.com/api/media/1b7cbb93-9836-4f7b-9f13-83dcc30274e4/video.mp4

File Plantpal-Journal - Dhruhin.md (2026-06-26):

# PlantPal — Journal Export

- Exported at: 2026-06-20T16:10:05Z
- Project ID: 2370
- Entries: 23

## Entry 1
- ID: 5692
- Author: Dhruhin
- Created At: 2026-05-06T06:09:40Z

### Content

I finally got a clear and working plan for the project! I spent time planning the system architecture, focusing on the two-device setup between the Hub and the Nodes. I also added a reliable backup system to ensure the outdoor node still functions if the Hub fails to connect.

Next, I defined how the emotion system of the project works, making sure it's simple and easy to understand. Alongside that, I designed the Hub system to work with multiple Nodes and also defined how the Hub recognizes each Node.

When planning the Hub, I had to decide whether I should go with a physical device or just an app. For now, I’ve decided to proceed with a physical device, since it feels more practical for the current concept, but I’m keeping the app option open for the future if needed.

I also reviewed similar existing products, which helped me understand that my project falls in the Premium Gardening & Horticulture space . That insight influenced few design decisions.

Then I brainstormed a few hardware additions like LED accents and a magnetic back to improve both functionality and aesthetics . Finally, with the help of ChatGPT and Gemini, I put together an initial design for both the Outdoor Node and the Hub. 

So in short, I’ve mapped out how the entire project will function end-to-end.

Hub Draft Design.jpeg
Node Draft Design.jpeg

### Recording Links

- https://public.lapse-hackclub.link/timelapses/WK7xKbXs_DTZ/timelapse-WK7xKbXs_DTZ.mp4
- https://public.lapse-hackclub.link/timelapses/CL8EHu1k5XNz/timelapse-CL8EHu1k5XNz.mp4

## Entry 2
- ID: 5903
- Author: Dhruhin
- Created At: 2026-05-07T14:14:27Z

### Content

Today I created the GitHub repository for PlantPal and set up the initial project structure. I organized folders for firmware, simulation, and documentation so the project stays clean and manageable as development continues.

After setting up the repository, I worked on writing the first README draft. I focused on explaining the main idea behind PlantPal, how the Hub and Outdoor Nodes work together, and how the emotion-based system makes plant care more intuitive and interactive.

I also added sections for system architecture, planned hardware, features, and future improvements so the repository gives a clear overview of the project and its long-term vision.

In the end, I had a properly organized GitHub repository and a completed README draft, giving the project a solid foundation for future development.




### Recording Links

- https://public.lapse-hackclub.link/timelapses/dq0RUUBd83Fb/timelapse-dq0RUUBd83Fb.mp4
- https://public.lapse-hackclub.link/timelapses/vrku-IpqXvnG/timelapse-vrku-IpqXvnG.mp4

## Entry 4
- ID: 6094
- Author: Dhruhin
- Created At: 2026-05-08T14:53:58Z

### Content

Today I mainly worked on making the BOM  for the PlantPal outdoor node and planning the electronics properly. I listed out the main parts like the ESP32, soil moisture sensor, temperature sensor, BH1750 light sensor, OLED display, LED strip, charging module, voltage regulator, battery, and solar panel.

I also spent time trying to understand how everything connects instead of just picking parts randomly. I checked prices, compatibility, and availability to make sure the setup is actually realistic.

This honestly made the project feel way more real because I could finally picture how all the hardware would come together instead of it just being random ideas in my head. It also made me feel a lot more confident since I understand the structure and electronics of the PlantPal outdoor node way better now.



### Recording Links

- https://public.lapse-hackclub.link/timelapses/8xWYj5SCap_P/timelapse-8xWYj5SCap_P.mp4

## Entry 6
- ID: 6145
- Author: Dhruhin
- Created At: 2026-05-08T19:38:48Z

### Content

Today I worked on planning the BOM for the PlantPal central hub. At first I thought it would be as same as the outdoor node in the context of difficulty and guess what I was right. It is such a struggle to find the right component for the right price and it also had to be available.

Most of the time I was just researching parts and figuring out what actually makes sense together. I looked at stuff like the ESP32, displays, power management, storage, RTC modules, connectors, and other small components. I also had to search the same product again and again since they were way to costly or unavailable.

This also helped me understand how everything connects together. By the end of the day the project felt way more real in my head and I feel a lot more confident about how it’s all going to work. Kudos to myself for actually completing the entire thing without breaking down!



### Recording Links

- https://public.lapse-hackclub.link/timelapses/yDhH1sWmtQS9/timelapse-yDhH1sWmtQS9.mp4

## Entry 9
- ID: 6471
- Author: Dhruhin
- Created At: 2026-05-10T18:28:50Z

### Content

At first I wanted to directly start writing the code for the emotion logic, but while setting up PlatformIO IDE my IDE was lagging so much that I genuinely lost patience. Then I realized I could literally use that waiting time to start researching instead.

At first I thought the whole emotion logic system would be straightforward and simple, but the deeper I went, the harder it got. The real struggle started when I realized my math wasn’t exactly wrong… just very inaccurate. Like I was like are you kidding me I literally thought my math is perfect just to get humbled few days later. I spent forever trying to fix the formulas and eventually got them working properly, but I used AI’s help to clean them up.

After that I started the actual plant research and somehow ended up discovering that plants can basically be grouped by their water retention behavior.  I spent a lot of time reading documentation and trying to understand the different plant types, but it quickly became way too much information to process normally. So instead, I used AI to summarize the plant categories into smaller and easier explanations that I could actually work with.

By the end of it all, I finally managed to piece everything together and honestly the entire logic system makes way more sense in my head now.


### Recording Links

- https://public.lapse-hackclub.link/timelapses/577JR8riJK8C/timelapse-577JR8riJK8C.mp4

## Entry 11
- ID: 6633
- Author: Dhruhin
- Created At: 2026-05-11T18:28:22Z

### Content

Hey, so finally my PlatformIO IDE was setup so now I could finally start the emotion logic, so I created the first part for the Central Hub. I basically started by setting up the PlatformIO ESP32-S3 project in VS Code and then organized the whole project into modular folders inside `lib/` so everything stays clean and easier to manage later. After that I created the main core system data structures inside `types.h` and built the overall `PlantProfile` blueprint structure which basically became the base for how plants work inside PlantPal.

Then I created the first real plant profile which was the  Xerophyte profile and added its sunlight ranges, moisture ranges, temperature ranges, and weight priorities for different environmental conditions. After that I built the `sensor_score_calculator` system to evaluate how suitable a condition is for a plant and connected it to the `score_calculator` system which calculates the final overall health score. Oh yeah so basically after yesterday's research I came to conclusion to make a score based on the readings of the sensors but guess what I forgot about it, but atleast I remembered it and did that too. So in short  I finally designed the full setup of the Emotion Logic of the Central Hub.



### Recording Links

- https://public.lapse-hackclub.link/timelapses/xyRklBYikdzx/timelapse-xyRklBYikdzx.mp4

## Entry 12
- ID: 6764
- Author: Dhruhin
- Created At: 2026-05-12T11:58:54Z

### Content

Today while completing the setup for the emotion logic of the central hub, I realized I had somehow forgotten to add the normalizer part. The moment I noticed it I was just like “Really? After all this?” so I quickly added it in and continued writing the code.

Then came the part that genuinely confused me for a while. I started debating with AI about the implementation of my formulas because something still felt off in the outputs. At first I thought AI was saying I messed up Formula 1 — the sensor normalizing formula — and I was defending it because technically the formula itself was correct. Turns out Formula 1 wasn’t even the issue. I literally just forgot to finish Formula 2 somehow. 

So basically I had two formulas:
* the sensor normalizing formula
* the score converter formula

And somehow I only wrote the code for the first one. Which means the program could normalize sensor readings, but it never properly converted those normalized values into finalized scores. Yeah… AI was right the whole time apparently. Not because my formula was wrong, but because I literally forgot to complete the second half of the logic. The worst part is I literally spent like 30 minutes tweaking these formulas the other day

Moving on, after finally understanding the issue, I set up the missing score conversion logic and continued building the health score system. Then right as I was saving the code, I randomly decided to ask AI for one final review. Good thing I did because I had somehow forgotten to define the multiplier values and also hadn’t implemented the danger counting system yet. So yeah… I added those too.

But after all of that, I can finally say I’m done with the setup for the emotion logic of the central hub. Honestly, this whole thing felt like one giant chain of “fix one thing, discover another missing thing,” but somehow it all came together in the end.

Kudos to myself for actually finishing it — and hopefully I didn’t forget anything else this time.





### Recording Links

- https://public.lapse-hackclub.link/timelapses/T-J5PLlt8xVm/timelapse-T-J5PLlt8xVm.mp4

## Entry 15
- ID: 6964
- Author: Dhruhin
- Created At: 2026-05-13T18:20:26Z

### Content

Today was honestly one of the most satisfying sessions I’ve had on the project so far because I finally completed writing the emotion logic system for the central hub and most importantly no mishaps. After spending so much time building the structure, debugging formulas, fixing missing logic, and connecting all the scoring systems together, I finally reached the point where I have built the heart of the project.

Hey now I can finally see the logic flow correctly from sensor readings → normalized values → converted scores → emotional interpretation was honestly a really satisfying moment because for the first time the system actually behaved the way I originally imagined it. 

I also finished writing all the plant profiles for every plant type in the project. I thought this part would be quick, but it ended up taking way longer because I wanted each plant to have its own behaviors, preferences, and proper setup connected to the health/emotion system. Now I could finally include personalization of specific plant types much better and looks like I brought proper use to my  research on plant types.

At first I was just gonna make the emotion levels super simple with every 20 health score for each level, but later after AI explained non-linear growth to me, I realized a custom scale would actually make the emotions feel way more natural instead of super flat and repetitive.

So by the end of today, I finally completed:

- the emotion logic system
- all the plant profiles

Crazy how I manage to all that in just a short portion of time ! 



### Recording Links

- https://lookout.hackclub.com/api/media/5151bebc-0cc5-4fe8-9795-6278d35b3cb5/video.mp4

## Entry 17
- ID: 7141
- Author: Dhruhin
- Created At: 2026-05-14T18:12:03Z

### Content

Today honestly felt like one of those sessions where the project started feeling more “alive” instead of just a collection of systems stitched together because I finally completed writing the connection logic and fallback logic for the central hub. After spending so much time thinking through all the possible failure cases, disconnects, retries, and recovery situations, I finally reached the point where the system could actually handle problems properly instead of instantly breaking the moment something went wrong.

After that, I moved on to working on the LED accent system which sounded extremely simple in my head at first… until I accidentally discovered how many shades of green exist. I genuinely thought it would just be “pick green” done. Absolutely not. Apparently there’s warm green, cool green, mint green, forest green, neon green, soft green, emerald green, muted green, and somehow every single one gave the entire setup a completely different mood. Finding the “right” green somehow became a side quest that took way longer than expected because even tiny adjustments completely changed how the LEDs felt. But once I finally started getting the accents looking the way I imagined, the whole setup instantly felt way more polished and alive.

And then came the humbling portion of today. At one point I asked AI to review my LED accent code because something felt off and I was convinced I probably messed up part of the logic. Turns out… I was correct. AI found bugs. So I fixed them. Then I asked it to check again. Another issue appeared.  So I fixed that too. Then another error showed up. And another.  At some point it honestly felt like every time I fixed one thing, the code unlocked a brand new problem just to keep me humble. Every time I thought - “Alright NOW it’s finally fixed.”  The code basically responded with  “Incorrect.”

But honestly, that entire process ended up helping a lot because every bug forced me to clean up the structure more properly instead of leaving hidden issues behind. By the end of it, the logic was not only working better, but the entire system also became cleaner and way more reliable than when I first started.







### Recording Links

- https://public.lapse-hackclub.link/timelapses/c9ZRulISw00Y/timelapse-c9ZRulISw00Y.mp4

## Entry 19
- ID: 7298
- Author: Dhruhin
- Created At: 2026-05-15T18:10:01Z

### Content

Today honestly felt pretty huge Win because the project I finally started working on the smart and cool features . I finished building the node identity system, so now nodes can properly recognize themselves, reconnect correctly, and recover without completely confusing the network every time something disconnects. Seeing that finally work smoothly was way more satisfying than I expected.

After that I worked on the sleep-aware feature which sounded super easy in my head at first. I thought it would basically just be “if late at night, go idle.” Yeah no. Turns out there’s a massive difference between idle, sleeping, disconnected, partially active, and silently failing. I spent way longer than expected understanding and tweaking timings and behaviors because even tiny changes completely changed how natural the system felt.

Then I worked on the water recovery feature which was honestly more interesting than I expected. The system now slowly moves through different recovery states instead of instantly jumping back to normal, so the transitions actually feel natural. I spent some time tweaking the recovery timing and emotion progression logic so it wouldn’t feel too fast or weirdly robotic. Once it finally started moving smoothly from critical states back to thriving properly, the whole system felt way more alive and polished.

And then came the smart analysis feature which was also the feature that let AI humble me for the rest of the session. Every time I fixed one analysis issue, another edge case randomly appeared somewhere else. It genuinely felt like the system was exposing every bad assumption I had hidden in the code. But honestly that helped a lot because by the end of it, the entire structure became way cleaner and more reliable than when I started.






### Recording Links

- https://public.lapse-hackclub.link/timelapses/kkSCzfPPqANP/timelapse-kkSCzfPPqANP.mp4

## Entry 20
- ID: 9098
- Author: Dhruhin
- Created At: 2026-05-25T12:30:17Z

### Content

Today’s session honestly felt super chaotic but ironically productive at the same time.

I started by writing the code for all the sensor modules which ended up being way more annoying and repetitive than I expected. Every sensor had its own weird little issues, so fixing one thing usually meant that the same problem occurred in the other codes.

After that I worked on the hysteresis feature and got humbled by math for way longer than I expected. Tiny value changes completely changed how the system behaved, so I spent a lot of time adjusting thresholds and timings just to make everything feel stable instead of random.

The biggest part of the session was definitely the trend analysis feature. I seriously underestimated how long it would take. The hardest part was figuring out what actually counts as a real trend instead of just random fluctuations. But once it finally started working properly, the whole system felt way smarter because it could understand patterns instead of reacting instantly to every small change.

I also worked on the system intelligence logic to make the system more context aware and natural overall. By the end of the session everything felt more connected and realistic.

The funniest part was getting absolutely humbled by debugging the analysis system. Every time I fixed one issue, another edge case appeared out of nowhere and exposed some terrible assumption in my code.

Even though the whole session was exhausting, finally completing all the code felt really satisfying. The system genuinely feels smarter and more advanced now than it did before. 








### Recording Links

- https://public.lapse-hackclub.link/timelapses/YzPbqTXbEmDx/timelapse-YzPbqTXbEmDx.mp4
- https://public.lapse-hackclub.link/timelapses/nlDZXo2E7Mip/timelapse-nlDZXo2E7Mip.mp4

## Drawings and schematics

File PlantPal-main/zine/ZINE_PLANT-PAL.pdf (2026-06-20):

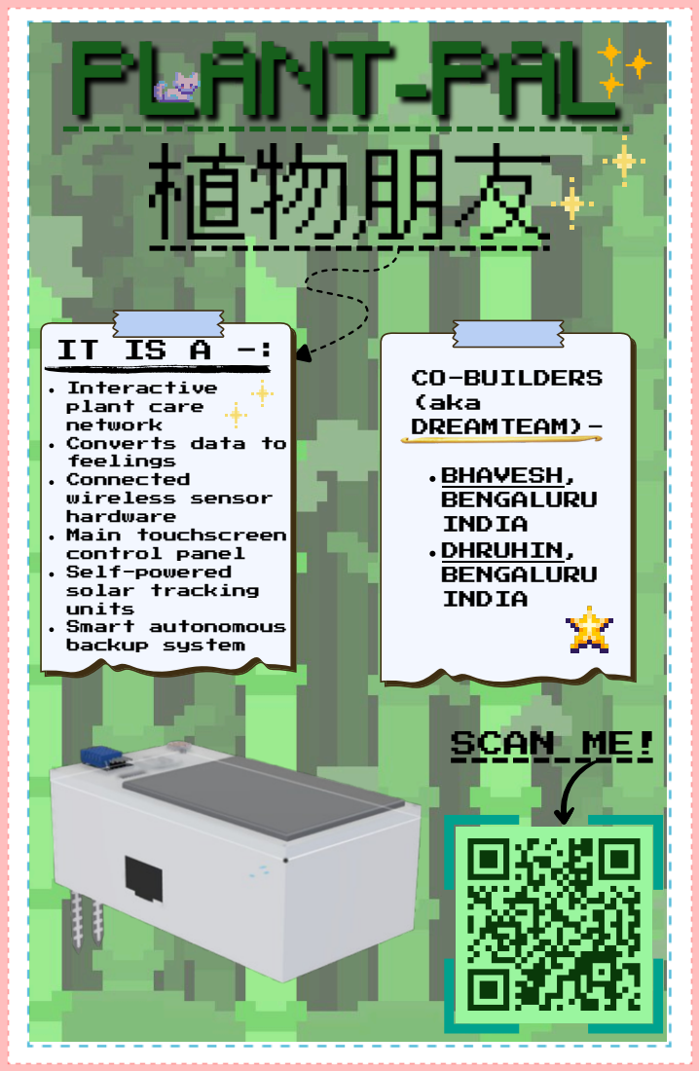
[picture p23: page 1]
CO-BUILDERS (aka DREAMTEAM)-; BHAVESH, BENGALURU INDIA; DHRUHIN, BENGALURU INDIA; SCAN ME!

Interactive
plant care
network
Converts data to
feelings
Connected
wireless sensor
hardware
Main touchscreen
control panel
Self-powered
solar tracking
units
Smart autonomous
backup system

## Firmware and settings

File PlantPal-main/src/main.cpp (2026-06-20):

#include <Arduino.h>

#include <types.h>
#include <constants.h>

#include <moisture.h>
#include <sunlight.h>
#include <temperature.h>

#include <wifi_manager.h>
#include <node_identity.h>

#include <sensor_normalizer.h>
#include <sensor_score_calculator.h>
#include <score_calculator.h>

#include <emotion_logic.h>
#include <hysteresis.h>

#include <trend_analysis.h>

#include <water_recovery.h>

#include <led_accent.h>

#include <smart_alerts.h>

#include <fallback_logic.h>

#include <mesophyte.h>

PlantProfile activeProfile =
    mesophyteProfile;

float anchorHealthScore =
    100.0;

Emotion activeEmotion =
    THRIVING;

void setup()
{
    Serial.begin(115200);

    initializeNodeID();

    initializeWiFi(
        "YOUR_WIFI_SSID",
        "YOUR_WIFI_PASSWORD"
    );

    initialMoistureSensor();

    initializeSunlightSensor();

    initializeTemperatureSensor();

    initializedLedAccent();
}

void loop()
{
    reconnectWiFi();

    SensorData sensorData;

    sensorData.moisture =
        readMoistureValue();

    sensorData.sunlight =
        readSunlightValue();

    sensorData.temperature =
        readTemperatureValue();

    float normalizedMoisture =
        normalizeValue(
            sensorData.moisture,
            RAW_MOISTURE_MIN,
            RAW_MOISTURE_MAX
        );

    float normalizedSunlight =
        normalizeValue(
            sensorData.sunlight,
            RAW_SUNLIGHT_MIN,
            RAW_SUNLIGHT_MAX
        );

    float normalizedTemperature =
        normalizeValue(
            sensorData.temperature,
            RAW_TEMPERATURE_MIN,
            RAW_TEMPERATURE_MAX
        );

    SensorScore scores;

    scores.moistureScore =
        calculateSensorScore(
            normalizedMoisture,
            activeProfile.moistureMin,
            activeProfile.moistureMax,
            1.0
        );

    scores.sunlightScore =
        calculateSensorScore(
            normalizedSunlight,
            activeProfile.sunlightMin,
            activeProfile.sunlightMax,
            1.0
        );

    scores.temperatureScore =
        calculateSensorScore(
            normalizedTemperature,
            activeProfile.temperatureMin,
            activeProfile.temperatureMax,
            1.0
        );

    float currentHealthScore =
        calculateHealthScore(
            scores,
            activeProfile,
            1.0
        );

    addHealthScore(
        currentHealthScore
    );

    Emotion candidateEmotion =
        getEmotionFromScore(
            currentHealthScore
        );

    if (
        shouldUpdateEmotion(
            anchorHealthScore,
            currentHealthScore,
            activeEmotion,
            candidateEmotion
        )
    )
    {
        activeEmotion =
            candidateEmotion;

        anchorHealthScore =
            currentHealthScore;
    }

    if (isRecoveryActive())
    {
        activeEmotion =
            updateRecovery();
    }

    updatedLEDAccent(
        activeEmotion
    );

    updateFallbackState(
        isWiFiConnected()
    );

    if (
        shouldSendAlert(
            currentHealthScore,
            activeEmotion
        )
    )
    {
        recordAlertSent();
    }

    Serial.print(
        "Health Score: "
    );

    Serial.println(
        currentHealthScore
    );

    Serial.print(
        "Predicted Health: "
    );

    Serial.println(
        predictFutureHealth(3)
    );

    delay(1000);
}

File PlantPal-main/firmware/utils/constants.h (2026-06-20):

#ifndef CONSTANTS_H
#define CONSTANTS_H

#define MOISTURE_SENSOR_PIN 34
#define SUNLIGHT_SENSOR_PIN 35
#define TEMPERATURE_SENSOR_PIN 32

#define RAW_MOISTURE_MIN 0.0
#define RAW_MOISTURE_MAX 1.0

#define RAW_SUNLIGHT_MIN 0.0
#define RAW_SUNLIGHT_MAX 1.0

#define RAW_TEMPERATURE_MIN 0.0
#define RAW_TEMPERATURE_MAX 1.0

#define WIFI_RECONNECT_INTERVAL 10000
#define HYSTERESIS_THRESHOLD 5.0
#define RECOVERY_INTERVAL 5000
#define ALERT_COOLDOWN 1800000

#define LED_COUNT 30
#define LED_PIN 5

#endif

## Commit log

2026-06-20 Initial PlantPal upload
    [18650-battery-and-holder-02b.f3d, 18650-battery-and-holder-02b.step, Aluminum_electrolytic_capacitor_radial_D8_H11.5_PinD0.6_Pitch3.5_nominal_black.f3d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]
2026-06-21 Update README, CAD, and project documentation
    [Body_electronics.step, Main_Body.f3d, Main_Body.step]
2026-06-22 Add Bom.csv and plantpal-journal.md to README
2026-06-30 Revise README for clarity and detail
    Updated the README to improve clarity and detail about the PlantPal project, including changes to descriptions, features, and assembly instructions.
2026-06-30 Update README with wiring diagram information
    Added a section about the wiring diagram and clarified the electronics connections.
2026-06-30 Update README for sensor reading details
    Clarified sensor reading process and threshold comparison.
